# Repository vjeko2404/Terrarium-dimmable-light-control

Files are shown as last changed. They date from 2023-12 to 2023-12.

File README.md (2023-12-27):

Programmable sunrise & sunset simulator with additional light alarm function and output to a 230V Schuko socket

I made this as a school project in 2022. The device can be used to dim the light in the terrarium. The 230V socket has a maximum output power of 500W.
The device can be connected to the home wifi to automatically synchronize time and location.
Basically, it automatically sets the sunrise and sunset time based on the location.
Read the main.pdf (in german language) in the documentation for more information.

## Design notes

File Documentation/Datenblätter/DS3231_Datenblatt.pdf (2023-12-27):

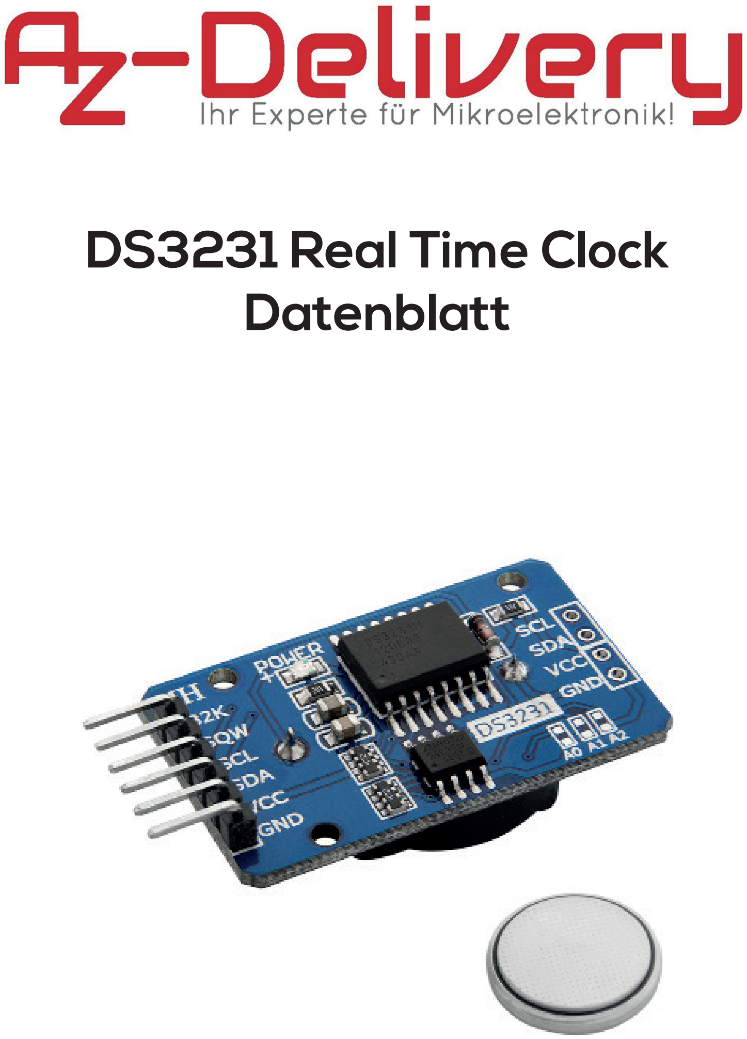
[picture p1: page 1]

# DS3231 Real Time Clock Datenblatt

Page 2

Content:

### 1. Specifications 2. Pinout 3. Connection Diagram

Page 3

### 1. Specifications

Power Supply Voltage | 3.3V
Operational Temperature | From 0 to +70 °C
Communication Interface | I2C
Battery Backup | One 3V Coin Cell Battery Batter holder
Digital Temp Sensor | ±3°C Accuracy
Programmable Square-Wave | 32kHz [Output]
Time of Day Alarms | 2
Low Power Consumption | Less Than 1mA
Dimensions | 34mm x 23mm x 18mm [1.3in x 09in x 07in]

The module consists of a DS3231 RTC Clock chip and Atmel AT24C32 EEPROM chip. The AT24C32 has memory storage capacity of 32kB and uses the I2C bus interface with 0x57 address which can be modified. It has a capability of setting the time and date, checking and clearing alarms and logging data with a timestamp.

The module has a battery holder for one 3V coin cell battery and the battery is included with the module. The battery serves as back-up power supply for the module. When external power supply is turned OFF, the automatic detection onboard chip switches to battery back-up.

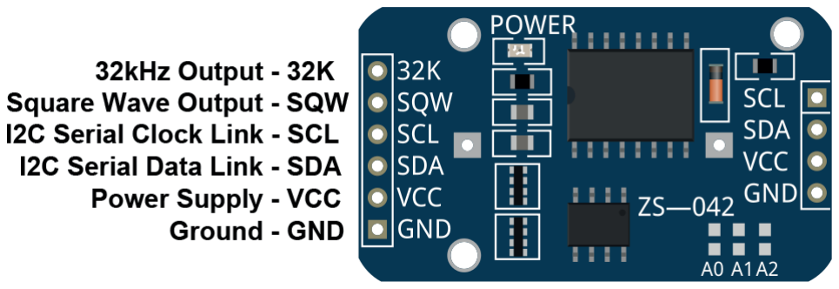
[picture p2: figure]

Page 4

### 2. Pinout

The DS3231 RTC module safely operates on 3.3V Voltage.
The 32K output pin is a crystal controlled oscillator output pin. It provides a 32kHz square-wave signal and it can be used to feed the reference signal for other devices. It may be left floating if not used.

The SQW pin can provide either an interrupt signal due to alarm conditions or a square-wave output signal.

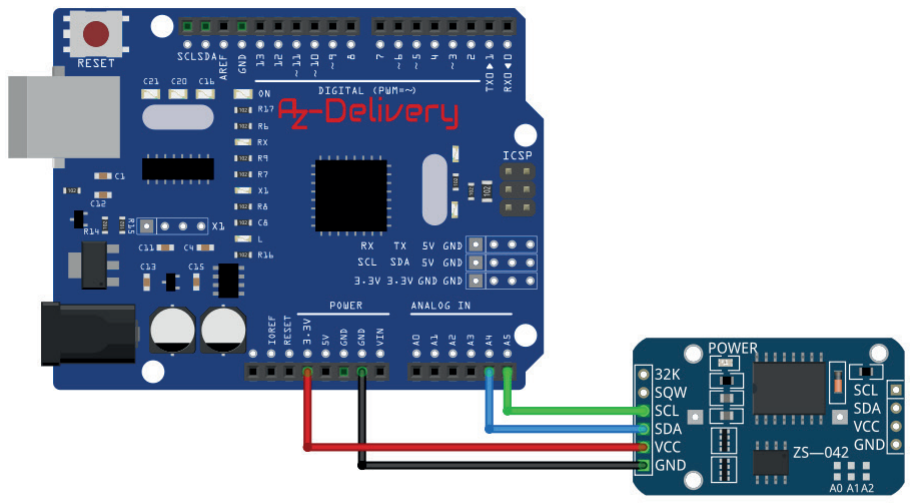
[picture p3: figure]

Page 5

### 3. Connection Diagram

Module Pin | Microcontroller Pin | Wire Color
SCL | A5 | Green Wire
SDA | A4 | Blue Wire
VCC | 3.3V | Red Wire
GND | GND | Black Wire

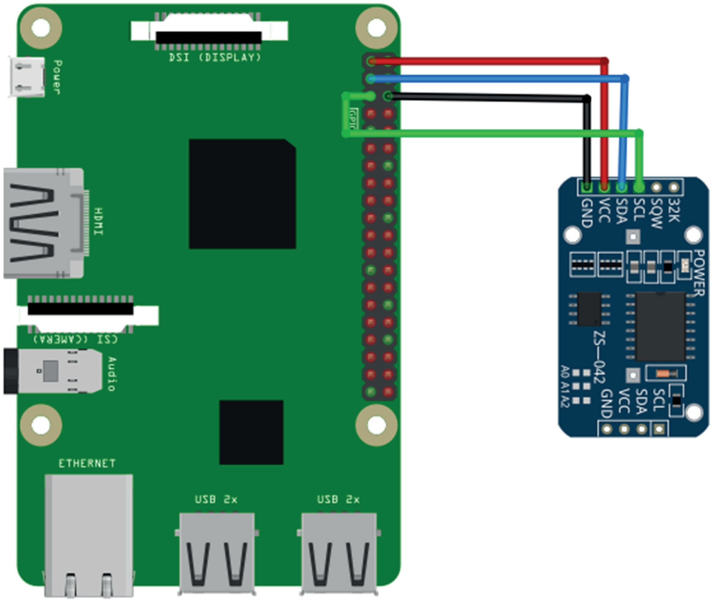
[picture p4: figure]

Page 6

Module Pin | Microcontroller Pin | Physical Pin | Wire Color
VCC | 3V3 | 1 | Red Wire
SDA | GPIO2 | 3 | Blue Wire
GND | GND | 6 | Black Wire
SCL | GPIO3 | 5 | Green Wire

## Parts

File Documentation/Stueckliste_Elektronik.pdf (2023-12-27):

Materialstückliste
ID | Name | BMK | Menge | ME | Herstellerbeschreibung | Hersteller | Preis
1 2 3 4 5 | 22uF 10V 22pF 22pF 22uF 10V 470uF | C1 C2 C3 C4 C5 | 1 1 1 1 1 | ST ST ST ST ST | NHG-A 470U 10 Elko, radial, 22µF, 10V, RM3,5, 1000h, 105°C, 20% KERKO-500 22P Keramik-Kondensator, 22 pF, 10 %, NPO, 500 V, RM 5 KERKO-500 22P Keramik-Kondensator, 22 pF, 10 %, NPO, 500 V, RM 5 NHG-A 470U 10 Elko, radial, 22µF, 10V, RM3,5, 1000h, 105°C, 20% NHG-A 1,0M 16 Elko, radial,470µF, 16V, RM5,0, 1000h, 105°C, 20% | Chong Murata Manufacturing Murata Manufacturing Chong Chong | 0,27 € 0,07 € 0,07 € 0,27 € 0,35 €
6 7 8 9 10 | 10uF 16V ATMEGA328P-PU IC-Sockel ESP-01 KY-040 | C6 CPU1 CPU1 CPU2 EN1 | 1 1 1 1 1 | ST ST ST ST ST | NHG-A 470U 10 Elko, radial, 10µF, 16V, RM3,5, 1000h, 105°C, 20% ATMEGA328P-PU GS 28-S ESP8266 ESP-01S Serielle WiFi Transceiver Module KY-040 Module | Chong Mikrochip Mikrochip Weewooday AZ-Delivery | 0,27 € 3,70 € 0,11 € 2,12 € 4,79 €
11 12 13 14 15 | 2,5A Feinsicherung Sicherungshalter Kaltgeräte Einbaubuchse 150mH 20x04 LCD+I2C | F1 F1 L_in L1 LCD1 | 1 1 1 1 1 | ST ST ST ST ST | Feinsicherung 5x20mm, träge 2,5A A19040900ux0294eu LSBCT L-11P 150M Stehende-Induktivität, 11P, Ferrit, 150M HD44780 2004 LCD Display | Eska Sourcing map Himetsuya Fastron group AZ-Delivery | 0,28 € 1,99 € 2,50 € 0,95 € 11,29 €
16 17 18 19 20 | EL817 330 Ohm 2.2 Kohm 1 Kohm 10 Kohm | O1 R1 R10 R11 R12 | 1 1 1 1 1 | ST ST ST ST ST | EL817MB 4 PIN DIP Phototransistor 1/4W 330 Widerstand, Kohleschicht, 330 Ohm, 0207, 250 mW, 5% 2,2K Widerstand, Metallschicht, 2,2 kOhm, 0207, 0,6 W, 1% E24 Kohleschicht 1/4W 1,0K 10,0K Widerstand, Metallschicht, 10,0 kOhm, 0207, 0,6 W, 1% | Everlight Yageo Yageo Yageo Yageo | 0,17 € 0,15 € 0,12 € 0,15 € 0,08 €
21 22 23 24 25 | 10 Kohm 330 Ohm 10 Kohm 10 Kohm 330 Ohm | R13 R2 R3 R4 R5 | 1 1 1 1 1 | ST ST ST ST ST | 10,0K Widerstand, Metallschicht, 10,0 kOhm, 0207, 0,6 W, 1% 1/4W 330 Widerstand, Kohleschicht, 330 Ohm, 0207, 250 mW, 5% 10,0K Widerstand, Metallschicht, 10,0 kOhm, 0207, 0,6 W, 1% 10,0K Widerstand, Metallschicht, 10,0 kOhm, 0207, 0,6 W, 1% 1/4W 330 Widerstand, Kohleschicht, 330 Ohm, 0207, 250 mW, 5% | Yageo Yageo Yageo Yageo Yageo | 0,08 € 0,15 € 0,08 € 0,08 € 0,15 €
26 27 28 29 30 | 330 Ohm 330 Ohm DS3231 Schuko Steckdose 16 A 250 V 230V/12V 3,6VA | R6 R7 RTC1 SD1 T1 | 1 1 1 1 1 | ST ST ST ST ST | 1/4W 330 Widerstand, Kohleschicht, 330 Ohm, 0207, 250 mW, 5% 1/4W 330 Widerstand, Kohleschicht, 330 Ohm, 0207, 250 mW, 5% RTC DS3231 1520 WW Schuko Steckdose 16 A 250 V Serie AS 500 250 V 387.12-1 Printtrafo, 3,6 VA, 12 V, 315 mA, RM 27,5 mm | Yageo Yageo AZ-Delivery Jung Gerth | 0,15 € 0,15 € 6,99 € 3,68 € 5,50 €
31 32 33 34 35 | MOC3020 BT136/600 DF08M LMO78_05-1.0 DF08M | TRI1 TRI2 U1 U2 U3 | 1 1 1 1 1 | ST ST ST ST ST | MOC 3020 OPTOKOPPLER =K3020 BT 136/600 TRIAC, 600 V, 4 A, TO-220 DF08M-FAI LMO78_05-1.0 DC/DC-Wandler, 5 W, 5 V, 1000 mA, SIL TO220 DF08M-FAI | Lite-On Inc. East semiconductor Fagor Gaptec Fagor | 0,28 € 0,70 € 0,32 € 4,10 € 0,32 €
36 37 38 | LMO78_05-1.0 JST-XH04 16MHz Quartz | U2 U9 X1 | 1 1 1 | ST ST ST | LMO78_03-1.0 DC/DC-Wandler, 5 W, 3.3 V, 1000 mA, SIL TO220 JST-XH04 IQD LFXTAL003240 Standardquarz, Grundton, 16 MHz | Gaptec GTIWung IQD | 4,10 € 0,01 € 0,32 €
| | | | | | Summe | 56,86 €

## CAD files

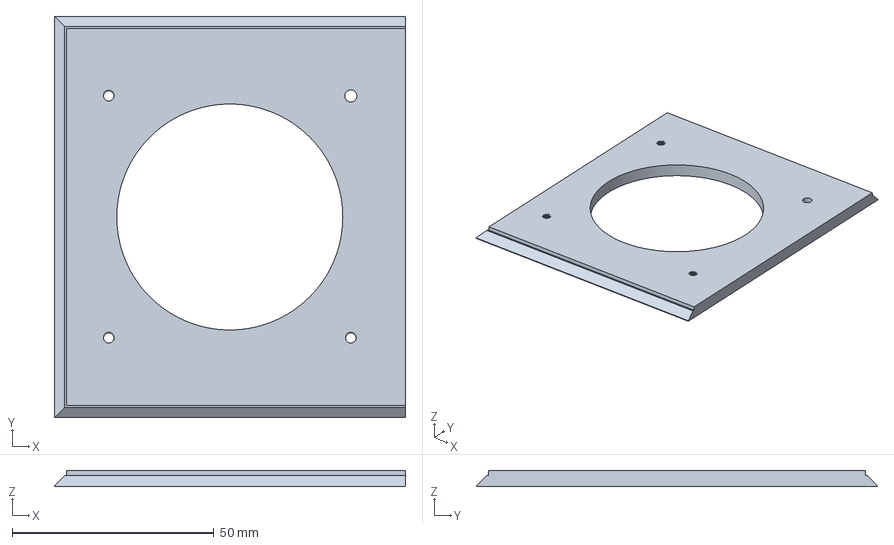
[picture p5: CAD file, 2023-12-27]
Hardware/STL/steckdose_platte.3mf
87.0 x 99.5 x 4.00 mm

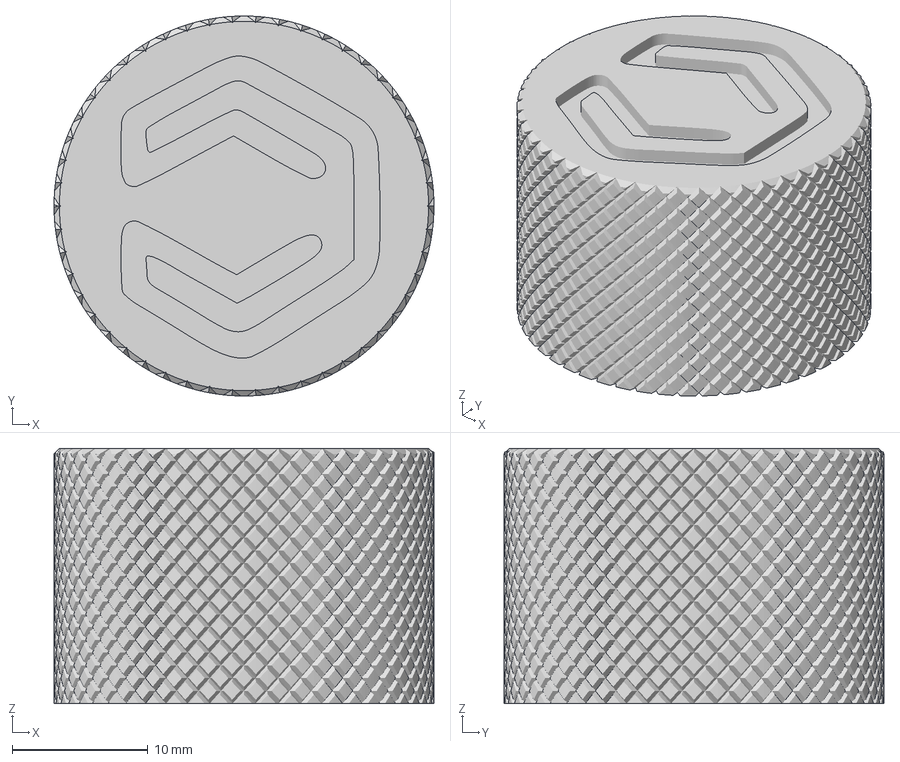
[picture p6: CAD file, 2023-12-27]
Hardware/STL/Drehgeberknopf.3mf
28.0 x 28.0 x 18.8 mm

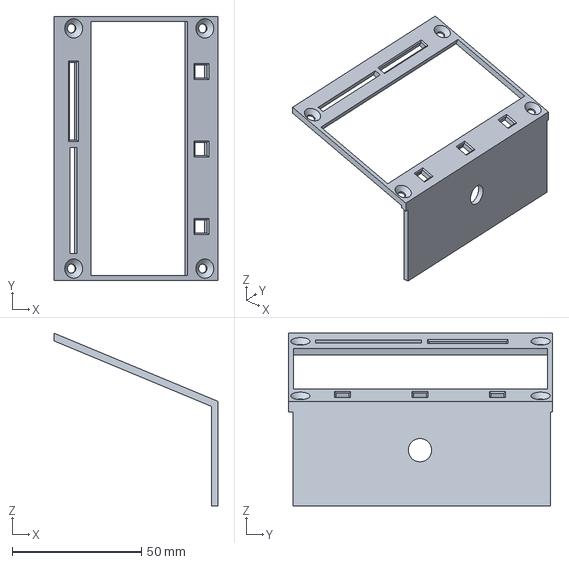
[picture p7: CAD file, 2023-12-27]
Hardware/STL/lcd_mask.3mf
63.4 x 102.2 x 66.8 mm

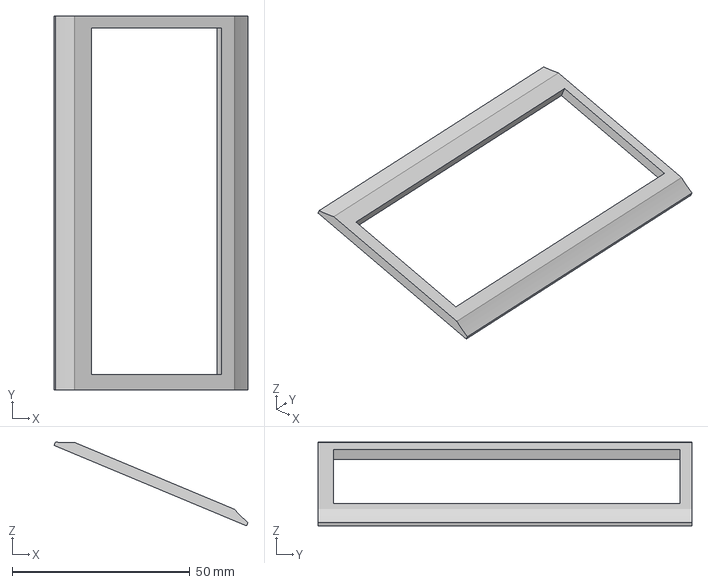
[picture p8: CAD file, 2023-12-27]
Hardware/STL/front_mask_2.3mf
54.6 x 105.2 x 23.6 mm

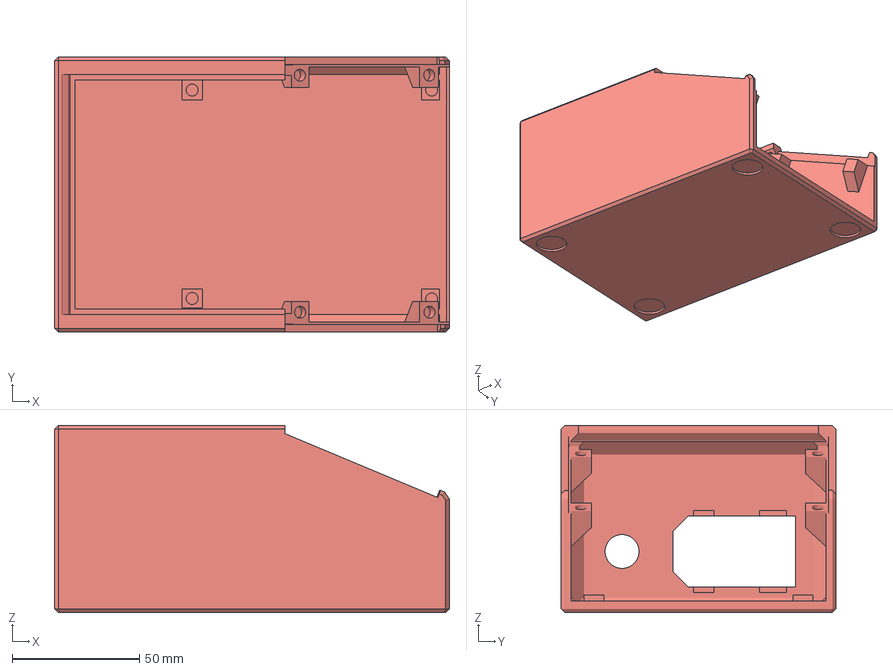
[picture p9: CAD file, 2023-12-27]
Hardware/STL/unterteil.3mf
155.0 x 108.0 x 73.5 mm

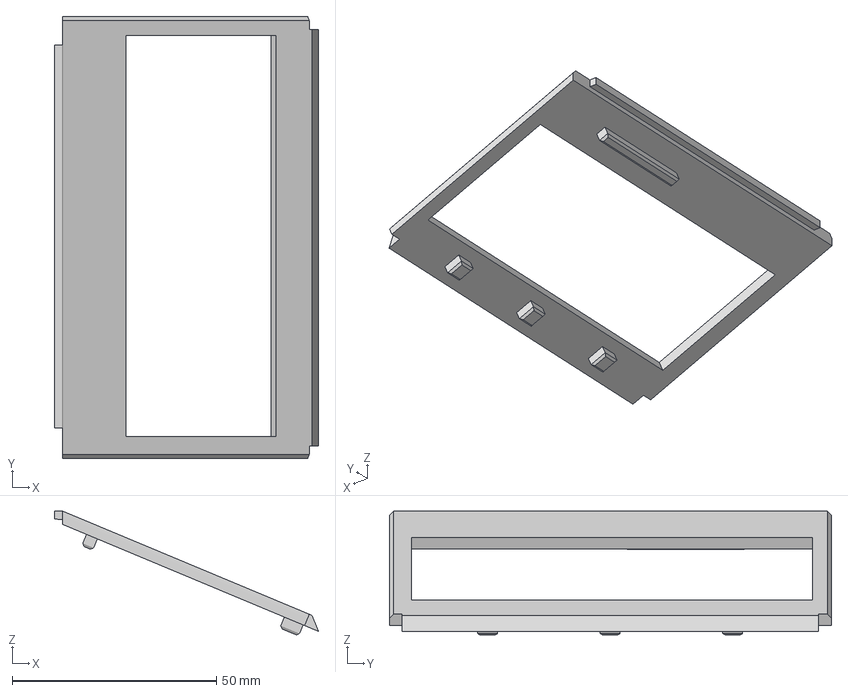
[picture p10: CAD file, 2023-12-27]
Hardware/STL/front_mask.3mf
64.7 x 108.2 x 30.3 mm

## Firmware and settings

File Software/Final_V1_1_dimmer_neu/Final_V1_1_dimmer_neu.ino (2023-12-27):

// *********************************************************************
// Bibliotheken laden
// *********************************************************************
//#include <NeoSWSerial.h>      // https://github.com/SlashDevin/NeoSWSerial -> DEBUG
#include <LiquidCrystal_I2C.h>  // https://github.com/johnrickman/LiquidCrystal_I2C
#include <LCDMenuLib2.h>        // https://github.com/Jomelo/LCDMenuLib2
#include <Encoder.h>            // https://github.com/PaulStoffregen/Encoder
#include <EEPROM.h>             // https://docs.arduino.cc/learn/built-in-libraries/eeprom
#include <DS3231.h>             // https://github.com/NorthernWidget/DS3231
#include <TriacDimmer.h>        // https://github.com/AJMansfield/TriacDimmer


// *********************************************************************
// LCDML LCD-Display Einstellungen
// *********************************************************************
#define _LCDML_DISP_cols 20
#define _LCDML_DISP_rows 4
#define _LCDML_DISP_cfg_cursor 0x7E  // Pfeil Symbol
#define _LCDML_DISP_cfg_scrollbar 0  // Scrollbar aktivieren 1=ein 0=aus - Kann 3,5% Programspeicher sparen!

// *********************************************************************
// Bibliothek-Einstellungen
// *********************************************************************

void lcdml_menu_display();
void lcdml_menu_clear();
void lcdml_menu_control();

unsigned char sync = 8;       // Nulldurchgang Pin
unsigned char triac = 9;      // AC Triac Pin

//NeoSWSerial ESP(7, 2);                                                                                                   // Software Serielle Pins für DEBUG definieren
DS3231 RTC;                                                                                                                // RTC Bibliothek start
LiquidCrystal_I2C lcd(0x27, _LCDML_DISP_cols, _LCDML_DISP_rows);                                                           // LCD Bibliothek start
LCDMenuLib2_menu LCDML_0(255, 0, 0, NULL, NULL);                                                                           // Stammmenüelement (nicht ändern)
LCDMenuLib2 LCDML(LCDML_0, _LCDML_DISP_rows, _LCDML_DISP_cols, lcdml_menu_display, lcdml_menu_clear, lcdml_menu_control);  // LCD-Menu Bibliothek start

// *********************************************************************
// Setup
// *********************************************************************
void setup()
// *********************************************************************
{
  //erster_start(); // <<<<<<<<<<<-------MUSS EINMAL AUSGEFÜHRT WERDEN !! EEPROM EINSTELLEN

  //ESP.begin(19200);                 // DEBUG !!!

  Serial.begin(115200);               // für interne ESP Strings lesen
  dimmer_setup();                     // Einrichtung in der Registerkarte zero_cross
  setup_menu();                       // Einrichtung in der Registerkarte LCDML_03011_i2c_display_20x4
  setup_rtc_variablen();              // Daten aus RTC in Varieblen speichern
  get_eeprom();                       // Daten aus EEPRROM auslesen und in Variablen speichern
}

// *********************************************************************
// Loop
// *********************************************************************
void loop()
// *********************************************************************
{
  LCD_Menu();                               // Hauptmenüschleife
  ESP_Receive_loop();                       // Daten vom ESP empfangen und in Variablen speichern
  dimmer_loop();                            // Dimmerwert lesen und Triac ansteuern
  rtc_aktualisierung();                     // Aktualisier die Variablen mit RTC Daten
  lichtwecker_zeitvergleich();              // Lichtwecker Zeitvergleicher 
  sonnen_zeitvergleicher();                 // Simulation Zeitvergleicher
  automatic_mode_loop();                    // 6_5_auto_mode
}

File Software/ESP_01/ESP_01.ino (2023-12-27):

// *********************************************************************
// Bibliotheken laden
// *********************************************************************
#include <SolarCalculator.h>      // https://github.com/jpb10/SolarCalculator
#include <ArduinoJson.h>          // https://github.com/bblanchon/ArduinoJson
#include <WiFiManager.h>          // https://github.com/tzapu/WiFiManager
#include <ESP8266WiFi.h>          // https://github.com/esp8266/Arduino/tree/master/libraries/ESP8266WiFi
#include <ESP8266WebServer.h>     // https://github.com/esp8266/Arduino/tree/master/libraries/ESP8266WebServer
#include <DNSServer.h>            // https://github.com/esp8266/Arduino/tree/master/libraries/DNSServer
#include <NTPClient.h>            // https://github.com/arduino-libraries/NTPClient
#include <WiFiUdp.h>              // https://github.com/esp8266/Arduino/tree/master/libraries/ESP8266WiFi
#include <ESP8266HTTPClient.h>    // https://github.com/esp8266/Arduino/tree/master/libraries/ESP8266HTTPClient
#include <time.h>                 // Standard C Bibliothek

IPAddress dns1(8, 8, 8, 8);  //Google dns
IPAddress dns2(8, 8, 4, 4);  //Alternate dns

// *********************************************************************
// Setup Allgemein
// *********************************************************************
void setup()
// *********************************************************************
{
  Serial.begin(115200);                        
  delay(100);
  setup_wlan_manager();
  setup_geodaten();
  setup_ntpdaten();
}

// *********************************************************************
// Setup Wlan-Manager
// *********************************************************************
bool wm_nonblocking = false;                  // change to true to use non blocking
WiFiManager wm;                               // global wm instance
WiFiManagerParameter custom_field;            // global param ( for non blocking w params )
// *********************************************************************
void setup_wlan_manager()
// *********************************************************************
{
  wm.setClass("invert");                                        //**********************************************//
  WiFi.begin();                                                 //                                              //
  delay(3000);                                                  //                   Startet den                //
  WiFi.mode(WIFI_STA);                                          //                   Wifi-Manager               //
  delay(1000);                                                  //                                              //
  WiFiManager wifiManager;                                      //**********************************************//
  wifiManager.setDebugOutput(false);                            // Debug-Ausgabe des Wifi-Managers ausschalten
  wifiManager.autoConnect("Terra-Lichtcontrol", "12345678");    // Standart Wlan Einstellung - SSID und Kennwort                               
}

// *********************************************************************
// Loop
// *********************************************************************
void loop()
// *********************************************************************
{
  showTime();
  atmega_read();
  Wifi_manager_reset();
  reconnect();
  geodaten();
  geo_reconnect();
  sonnendaten_berechnen();
  sonnendaten();
  time_sync();
  geo_sync();
  wlan_status();
  //parsing();
}

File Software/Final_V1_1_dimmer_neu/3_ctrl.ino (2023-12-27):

// *********************************************************************
// Drehgeber Einstellungen
// *********************************************************************
#define encoder_A_pin 6       // ATMEGA328P Pinnummer 6 (Drehgeber rechts)
#define encoder_B_pin 5       // ATMEGA328P Pinnummer 5 (Drehgeber links)
#define encoder_button_pin 4  // ATMEGA328P Pinnummer 4 (Drehgeber-Taste)

#define g_LCDML_CONTROL_button_long_press 800   // ms
#define g_LCDML_CONTROL_button_short_press 120  // ms

Encoder ENCODER(encoder_A_pin, encoder_B_pin);

unsigned long g_LCDML_CONTROL_button_press_time = millis();
bool g_LCDML_CONTROL_button_prev = HIGH;

// *********************************************************************
// Drehgeber loop
// *********************************************************************
void lcdml_menu_control(void)
// *********************************************************************
{
  // Variable für diese Funktion deklarieren
  int32_t g_LCDML_CONTROL_Encoder_position = ENCODER.read();
  bool g_LCDML_button = digitalRead(encoder_button_pin);

  if (LCDML.BT_setup()) {
    // Init-Pins, Pullups aktivieren
    pinMode(encoder_A_pin, INPUT);
    pinMode(encoder_B_pin, INPUT);
    pinMode(encoder_button_pin, INPUT);
  }
  // Prüfung, ob der Encoder in Richtung A gedreht wird
  if (g_LCDML_CONTROL_Encoder_position <= -3) {
    // Prüfung, ob die Taste gedrückt und der Encoder gedreht wird
    // die Taste ist low-aktiv
    if (g_LCDML_button == LOW) {
      // Taste wird gedrückt
      LCDML.BT_left();
      // Reset-Taste drücken Zeit für nächste Erkennung
      g_LCDML_CONTROL_button_prev = HIGH;
    } else {
      LCDML.BT_down();
    }
    // Init-Encoder für den nächsten Schritt
    ENCODER.write(g_LCDML_CONTROL_Encoder_position + 4);
  }
  // Prüfung, ob der Encoder in Richtung B gedreht wird
  else if (g_LCDML_CONTROL_Encoder_position >= 3) {
    // Prüfung, ob die Taste gedrückt und der Encoder gedreht wird
    // die Taste ist low-aktiv
    if (g_LCDML_button == LOW) {
      // Taste wird gedrückt
      LCDML.BT_right();
      // Reset-Taste drücken Zeit für nächste Erkennung
      g_LCDML_CONTROL_button_prev = HIGH;
    } else {
      LCDML.BT_up();
    }
    // Init-Encoder für den nächsten Schritt
    ENCODER.write(g_LCDML_CONTROL_Encoder_position - 4);
  } else {
    // prüfen, ob die Taste kurz oder lange gedrückt wurde
    //  fallende Flanke, Taste gedrückt, keine Aktion
    if (g_LCDML_button == LOW && g_LCDML_CONTROL_button_prev == HIGH) {
      g_LCDML_CONTROL_button_prev = LOW;
      g_LCDML_CONTROL_button_press_time = millis();
    }
    // steigende Flanke, Taste nicht gedrückt, prüfen, wie lange sie gedrückt war
    else if (g_LCDML_button == HIGH && g_LCDML_CONTROL_button_prev == LOW) {
      g_LCDML_CONTROL_button_prev = HIGH;
      // prüfen, wie lange die Taste gedrückt wurde, und erkennen, ob sie lange oder kurz gedrückt wurde
      // Prüfung der Lage der langer Tastendruck
      if ((millis() - g_LCDML_CONTROL_button_press_time) >= g_LCDML_CONTROL_button_long_press) {
        // Langer Tastendruck erkannt
        LCDML.BT_quit();
      }
      // Prüfung der Lage der kurzer Tastendruck
      else if ((millis() - g_LCDML_CONTROL_button_press_time) >= g_LCDML_CONTROL_button_short_press) {
        // Kurzer Tastendruck erkannt
        LCDML.BT_enter();
      }
    }
    // reserve
    else {
      // reserver
    }
  }
}
